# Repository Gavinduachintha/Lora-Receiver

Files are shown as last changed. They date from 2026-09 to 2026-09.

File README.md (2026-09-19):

# LoRa Tracker

A custom Raspberry Pi Pico 2-based LoRa receiver board designed and built as the **base station receiver for the [WildLife AI project](https://github.com/Gavinduachintha/WildLife_AI)**.

The board receives real-time LoRa packets transmitted by the remote wildlife monitoring unit and provides the hardware interface required for the base station display and power system.

## Project Preview
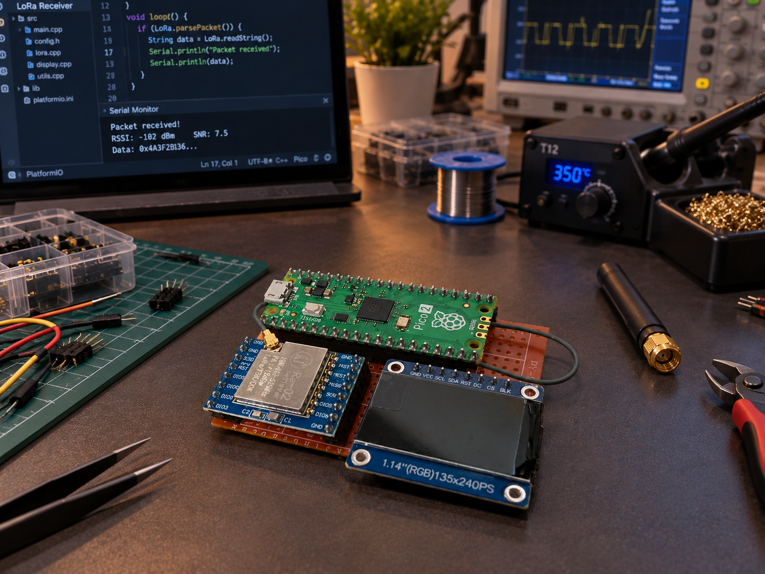
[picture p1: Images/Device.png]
LoRa Tracker Image/board preview


## Overview

The LoRa Tracker is a custom PCB designed to serve as the receiver unit of the WildLife AI system.

It integrates a **Raspberry Pi Pico 2** with dedicated interfaces for the LoRa transceiver, display, and battery power. The board replaces the earlier breadboard-based receiver prototype with a compact and more reliable PCB-based design.

### Main functions

* Receives data from the remote WildLife AI monitoring device through LoRa
* Provides an interface between the LoRa transceiver and Raspberry Pi Pico 2
* Connects to a small color display for receiver-side information
* Provides battery-powered operation
* Includes an onboard power switch
* Provides dedicated headers for external module connections

## Hardware

### Main Controller

* **Raspberry Pi Pico 2**
* RP2350-based microcontroller
* Used as the main controller for the receiver
* Handles incoming LoRa packets and receiver-side processing

### LoRa Interface

The PCB provides dedicated headers for connecting the LoRa transceiver module.

Supported interface signals include:

* MOSI
* MISO
* SCK
* NSS / CS
* RST / RES
* VCC
* GND

### Display Interface

A dedicated 8-pin header is provided for connecting the receiver display.

The interface includes signals such as:

* SCL
* SDA
* BLK
* VCC
* GND

### Power

The board includes:

* 2-pin JST battery connector
* Onboard SPST power switch
* Dedicated power connections for the controller and connected modules

## PCB Design

The board was designed using **KiCad** with the Raspberry Pi Pico 2 positioned as the main controller module.

The PCB provides dedicated connection points for the LoRa module, display, and battery, allowing the receiver to be assembled without the wiring complexity of the original prototype.

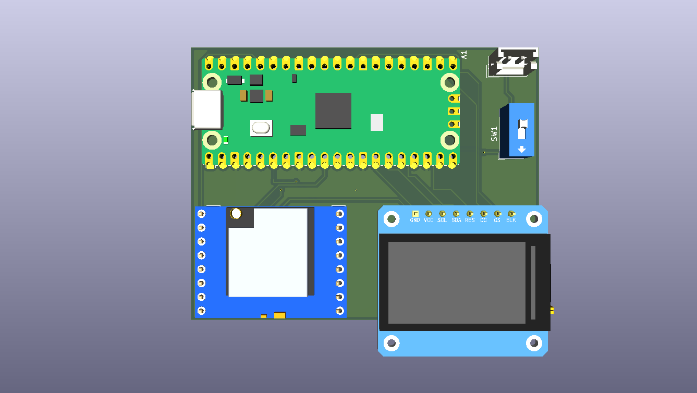
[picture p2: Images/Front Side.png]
Front Side PCB

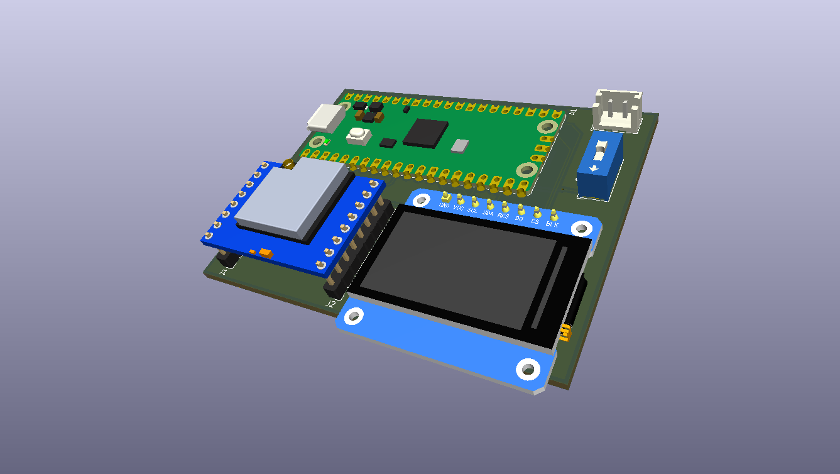
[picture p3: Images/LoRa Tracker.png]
LoRa Tracker assembled/board preview


## Repository Structure

```text
.
├── LoRa Tracker.kicad_pro   # KiCad project
├── LoRa Tracker.kicad_sch   # Schematic
├── LoRa Tracker.kicad_pcb   # PCB layout
└── Images/
    ├── Front Side.png
    └── LoRa Tracker.png
```

## Opening the Project

The project was designed using KiCad.

Open:

```text
LoRa Tracker.kicad_pro
```

from KiCad to access the schematic and PCB layout.

## WildLife AI Integration

This receiver is part of the **WildLife AI** system.

The overall system consists of a remote monitoring device and this receiver/base station.

```text
Remote Wildlife Monitor
        │
        │  LoRa
        ▼
┌─────────────────────┐
│   LoRa Tracker      │
│   Base Station      │
│                     │
│  Raspberry Pi Pico 2│
│  LoRa Interface     │
│  Display Interface  │
└─────────────────────┘
```

The remote unit collects information in the field and transmits it wirelessly through LoRa. The LoRa Tracker receives those packets and acts as the hardware foundation of the base station.

Learn more about the complete system:

[WildLife AI](https://github.com/Gavinduachintha/WildLife_AI)

## Development Workflow

Before manufacturing or modifying the board, the following checks should be performed:

* Review schematic connectivity
* Run KiCad ERC
* Run KiCad DRC
* Verify connector pinouts
* Verify component footprints and orientations
* Check the PCB edge cuts
* Generate fabrication files
* Assemble and test the hardware

## Current Status

The PCB has been designed and built as the **receiver/base station hardware for the WildLife AI project**.

The repository contains the KiCad source files required to inspect and continue development of the board.

## Future Hardware Improvements

Possible future revisions may include:

* Improved printed enclosure
* More integrated LoRa module mounting
* Additional status indicators
* Improved power management
* Further PCB size and connector optimization
* Improved connection distance
* Improved GUI with menu based navigation

## License

This project is licensed under the **Apache License 2.0**.

You are free to use, modify, and distribute this project in accordance with the terms of the license.

See the [`LICENSE`](LICENSE) file for the full license text.

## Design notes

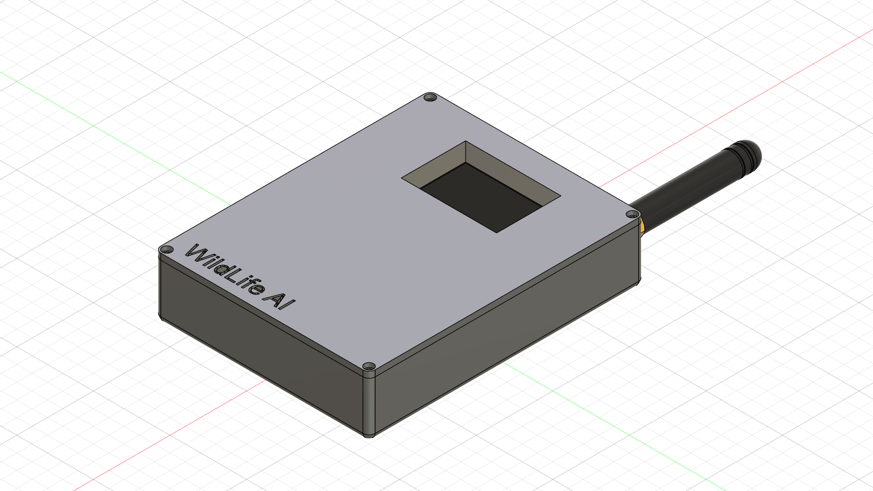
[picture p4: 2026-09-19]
Images/Tracker Box.png

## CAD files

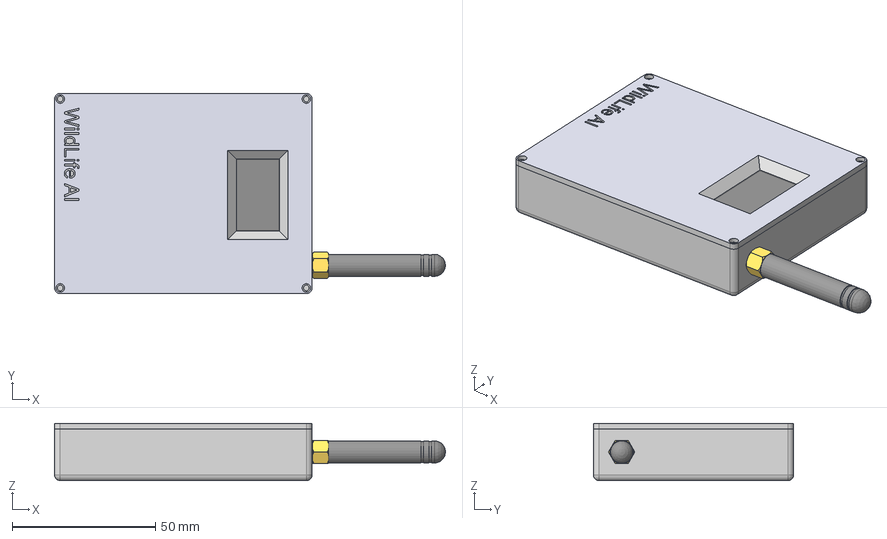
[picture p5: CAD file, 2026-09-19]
CAD File/Tracker Box.step
136.6 x 70.0 x 20.0 mm

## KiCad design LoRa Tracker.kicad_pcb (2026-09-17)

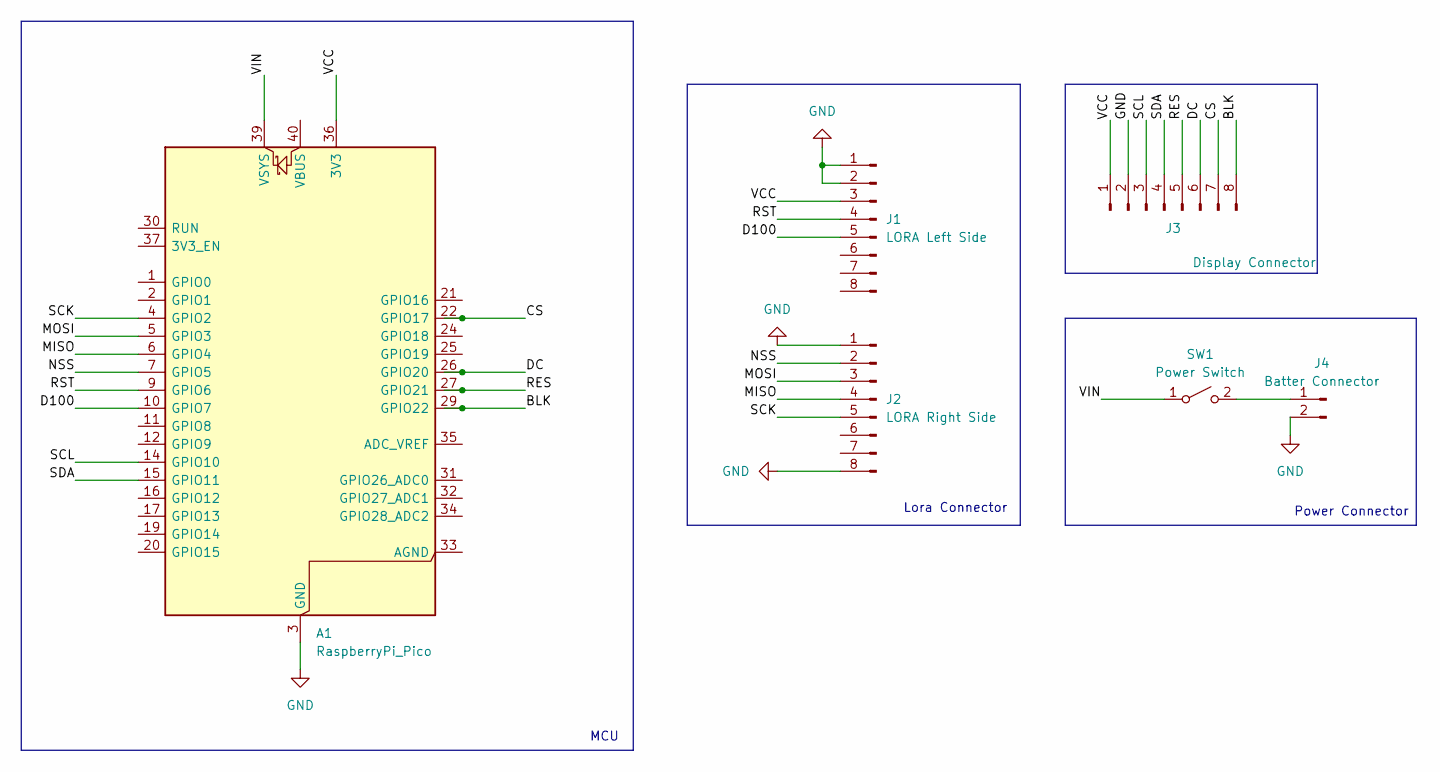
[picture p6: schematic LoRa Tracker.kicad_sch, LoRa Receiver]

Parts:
A1: RaspberryPi_Pico; RaspberryPi_Pico_Common_Unspecified
J1: LORA Left Side; PinHeader_1x08_P2.54mm_Vertical
J2: LORA Right Side; PinHeader_1x08_P2.54mm_Vertical
J3: Display Connector; PinHeader_1x08_P2.54mm_Vertical
J4: Batter Connector; JST_EH_B2B-EH-A_1x02_P2.50mm_Vertical
SW1: Power Switch; SW_DIP_SPSTx01_Slide_9.78x4.72mm_W7.62mm_P2.54mm

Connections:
/BLK: A1.29 (GPIO22), J3.8
/CS: A1.22 (GPIO17), J3.7
/D100: A1.10 (GPIO7), J1.5
/DC: A1.26 (GPIO20), J3.6
/MISO: A1.6 (GPIO4), J2.4
/MOSI: A1.5 (GPIO3), J2.3
/NSS: A1.7 (GPIO5), J2.2
/RES: A1.27 (GPIO21), J3.5
/RST: A1.9 (GPIO6), J1.4
/SCK: A1.4 (GPIO2), J2.5
/SCL: A1.14 (GPIO10), J3.3
/SDA: A1.15 (GPIO11), J3.4
/VCC: A1.36 (3V3), J1.3, J3.1
/VIN: A1.39 (VSYS), SW1.1 (A)
GND: A1.3 (GND), A1.8 (GND), A1.13 (GND), A1.18 (GND), A1.23 (GND), A1.28 (GND), A1.38 (GND), J1.1, J1.2, J2.1, J2.8, J3.2, J4.2
unnamed: J4.1, SW1.2 (B)

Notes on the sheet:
MCU
Lora Connector
Power Connector

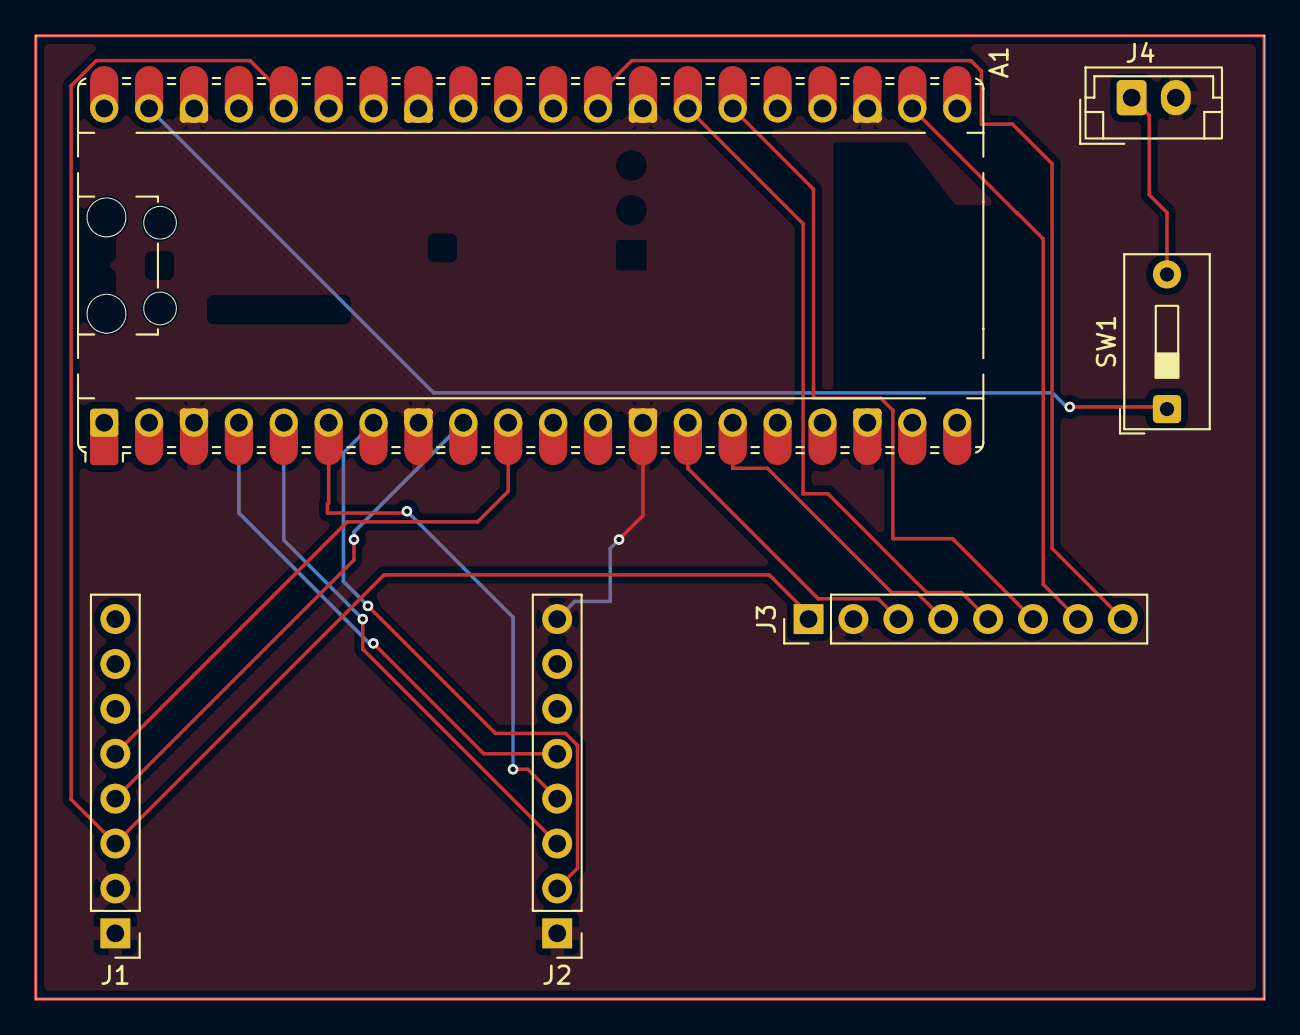
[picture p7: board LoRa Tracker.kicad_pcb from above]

Board: 2 copper layers, 69.5 x 54.5 mm, 6 parts (0 on the bottom side), 16 nets.

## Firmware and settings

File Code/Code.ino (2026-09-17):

#include <SPI.h>
#include <Adafruit_GFX.h>
#include <Adafruit_ST7789.h>

// =====================================================
// SX1278 LORA PINS
// =====================================================
#define LORA_SCK 2
#define LORA_MOSI 3
#define LORA_MISO 4
#define LORA_CS 5
#define LORA_RST 6
#define LORA_DIO0 7

// =====================================================
// ST7789 DISPLAY PINS
// =====================================================
#define TFT_SCK 10
#define TFT_MOSI 11
#define TFT_CS 17
#define TFT_DC 20
#define TFT_RST 21
#define TFT_BLK 22

#define TFT_WIDTH 240
#define TFT_HEIGHT 135

// =====================================================
// SX1278 REGISTERS
// =====================================================
#define REG_FIFO 0x00
#define REG_OP_MODE 0x01
#define REG_FRF_MSB 0x06
#define REG_FRF_MID 0x07
#define REG_FRF_LSB 0x08
#define REG_FIFO_RX_CURRENT 0x10
#define REG_IRQ_FLAGS 0x12
#define REG_RX_NB_BYTES 0x13
#define REG_FIFO_ADDR_PTR 0x0D
#define REG_MODEM_CONFIG1 0x1D
#define REG_MODEM_CONFIG2 0x1E
#define REG_MODEM_CONFIG3 0x26
#define REG_PREAMBLE_MSB 0x20
#define REG_PREAMBLE_LSB 0x21
#define REG_SYNC_WORD 0x39
#define REG_VERSION 0x42

#define LONG_RANGE_MODE 0x80
#define MODE_SLEEP 0x00
#define MODE_STDBY 0x01
#define MODE_RX_CONTINUOUS 0x05

#define IRQ_RX_DONE 0x40
#define IRQ_PAYLOAD_CRC_ERROR 0x20

// =====================================================
// LORA SPI
// =====================================================
SPISettings loraSPI(1000000, MSBFIRST, SPI_MODE0);

// =====================================================
// DISPLAY (SPI1)
// =====================================================
SPIClassRP2040 displaySPI(spi1, 12, TFT_CS, TFT_SCK, TFT_MOSI);

Adafruit_ST7789 tft(&displaySPI, TFT_CS, TFT_DC, TFT_RST);

// =====================================================
// GLOBAL VARIABLES
// =====================================================
uint32_t packetCount = 0;
String lastMessage = "Waiting for message...";
String latitude = "--";
String longitude = "--";
bool hasLocation = false;

// =====================================================
// LORA REGISTER FUNCTIONS
// =====================================================
void writeRegister(uint8_t reg, uint8_t value) {
  SPI.beginTransaction(loraSPI);
  digitalWrite(LORA_CS, LOW);
  SPI.transfer(reg | 0x80);
  SPI.transfer(value);
  digitalWrite(LORA_CS, HIGH);
  SPI.endTransaction();
}

uint8_t readRegister(uint8_t reg) {
  SPI.beginTransaction(loraSPI);
  digitalWrite(LORA_CS, LOW);
  SPI.transfer(reg & 0x7F);
  uint8_t value = SPI.transfer(0x00);
  digitalWrite(LORA_CS, HIGH);
  SPI.endTransaction();
  return value;
}

void resetLoRa() {
  digitalWrite(LORA_RST, LOW);
  delay(10);
  digitalWrite(LORA_RST, HIGH);
  delay(10);
}

void setFrequency(long frequency) {
  uint32_t frf = (uint32_t)((frequency / 32000000.0) * 524288);
  writeRegister(REG_FRF_MSB, (frf >> 16) & 0xFF);
  writeRegister(REG_FRF_MID, (frf >> 8) & 0xFF);
  writeRegister(REG_FRF_LSB, frf & 0xFF);
}

// =====================================================
// DISPLAY FUNCTIONS
// =====================================================
void drawHeader() {
  tft.fillRect(0, 0, 240, 26, ST77XX_BLUE);
  tft.setTextColor(ST77XX_WHITE);
  tft.setTextSize(2);
  tft.setCursor(8, 5);
  tft.print("LORA RECEIVER");
  tft.fillCircle(226, 13, 5, ST77XX_GREEN);
}

void drawStatusBar() {
  tft.fillRect(0, 117, 240, 18, ST77XX_BLACK);
  tft.setTextSize(1);
  tft.setTextColor(ST77XX_WHITE);
  tft.setCursor(5, 122);
  tft.print("433MHz  SF7  BW125");
  tft.setCursor(175, 122);
  tft.print("#");
  tft.print(packetCount);
}

void displayStartup() {
  tft.fillScreen(ST77XX_BLACK);
  tft.setTextColor(ST77XX_CYAN);
  tft.setTextSize(2);
  tft.setCursor(40, 25);
  tft.print("LORA");
  tft.setCursor(30, 50);
  tft.print("RECEIVER");

  tft.setTextColor(ST77XX_WHITE);
  tft.setTextSize(1);
  tft.setCursor(45, 80);
  tft.print("SX1278  |  433 MHz");
  tft.setCursor(60, 100);
  tft.print("Initializing...");
  delay(1500);

  tft.fillScreen(ST77XX_BLACK);
  drawHeader();
  tft.setTextColor(ST77XX_YELLOW);
  tft.setTextSize(1);
  tft.setCursor(25, 55);
  tft.print("Waiting for LoRa message...");
  drawStatusBar();
}

void displayMessage(String message) {
  tft.fillScreen(ST77XX_BLACK);
  drawHeader();

  // ---- Parse location from message ----
  hasLocation = false;
  latitude = "--";
  longitude = "--";

  int latIndex = message.indexOf("LAT:");
  int lonIndex = message.indexOf("LON:");

  if (latIndex != -1 && lonIndex != -1) {
    // Extract Latitude
    int latStart = latIndex + 4;
    int latEnd = message.indexOf(' ', latStart);
    if (latEnd == -1) latEnd = message.length();
    latitude = message.substring(latStart, latEnd);
    latitude.trim();

    // Extract Longitude
    int lonStart = lonIndex + 4;
    int lonEnd = message.indexOf(' ', lonStart);
    if (lonEnd == -1) lonEnd = message.length();
    longitude = message.substring(lonStart, lonEnd);
    longitude.trim();

    hasLocation = true;
  }

  // ---- Main Title ----
  tft.setTextColor(ST77XX_CYAN);
  tft.setTextSize(1);
  tft.setCursor(8, 32);
  tft.print("ALERT");

  tft.setTextColor(ST77XX_WHITE);
  tft.setTextSize(2);
  tft.setCursor(8, 45);
  tft.print("PERSON DETECTED");

  // ---- Location Section ----
  tft.setTextColor(ST77XX_YELLOW);
  tft.setTextSize(1);
  tft.setCursor(8, 72);
  tft.print("LOCATION");

  tft.setTextColor(ST77XX_WHITE);
  tft.setTextSize(1);

  if (hasLocation) {
    tft.setCursor(8, 88);
    tft.print("Lat: ");
    tft.print(latitude);

    tft.setCursor(8, 102);
    tft.print("Lon: ");
    tft.print(longitude);
  } else {
    tft.setCursor(8, 90);
    tft.setTextColor(ST77XX_RED);
    tft.print("GPS: NO FIX");
  }

  drawStatusBar();
}

void displayCRCError() {
  tft.fillScreen(ST77XX_BLACK);
  drawHeader();

  tft.setTextColor(ST77XX_RED);
  tft.setTextSize(2);
  tft.setCursor(50, 50);
  tft.print("CRC ERROR");

  tft.setTextColor(ST77XX_WHITE);
  tft.setTextSize(1);
  tft.setCursor(30, 85);
  tft.print("Corrupted packet received");
  drawStatusBar();
  delay(800);
}

// =====================================================
// LORA SETUP
// =====================================================
void setupLoRa() {
  resetLoRa();

  uint8_t version = readRegister(REG_VERSION);
  Serial.print("SX1278 Version: 0x");
  Serial.println(version, HEX);

  writeRegister(REG_OP_MODE, LONG_RANGE_MODE | MODE_SLEEP);
  delay(10);
  writeRegister(REG_OP_MODE, LONG_RANGE_MODE | MODE_STDBY);

  setFrequency(433000000);

  writeRegister(REG_MODEM_CONFIG1, 0x72);  // BW=125kHz, CR=4/5
  writeRegister(REG_MODEM_CONFIG2, 0x74);  // SF7 + CRC
  writeRegister(REG_MODEM_CONFIG3, 0x04);
  writeRegister(REG_PREAMBLE_MSB, 0x00);
  writeRegister(REG_PREAMBLE_LSB, 0x08);
  writeRegister(REG_SYNC_WORD, 0x12);
  writeRegister(REG_IRQ_FLAGS, 0xFF);

  writeRegister(REG_OP_MODE, LONG_RANGE_MODE | MODE_RX_CONTINUOUS);
  Serial.println("LoRa receiver ready.");
}

// =====================================================
// RECEIVE PACKET
// =====================================================
void receivePacket() {
  uint8_t irq = readRegister(REG_IRQ_FLAGS);

  if (!(irq & IRQ_RX_DONE)) return;

  if (irq & IRQ_PAYLOAD_CRC_ERROR) {
    Serial.println("CRC ERROR");
    displayCRCError();
    writeRegister(REG_IRQ_FLAGS, 0xFF);
    return;
  }

  uint8_t length = readRegister(REG_RX_NB_BYTES);
  uint8_t fifoAddress = readRegister(REG_FIFO_RX_CURRENT);
  writeRegister(REG_FIFO_ADDR_PTR, fifoAddress);

  String message = "";
  Serial.print("Received: ");

  for (uint8_t i = 0; i < length; i++) {
    uint8_t data = readRegister(REG_FIFO);
    Serial.write(data);
    message += (char)data;
  }
  Serial.println();

  packetCount++;
  lastMessage = message;

  displayMessage(message);  // Updated display function

  writeRegister(REG_IRQ_FLAGS, 0xFF);
}

// =====================================================
// SETUP
// =====================================================
void setup() {
  Serial.begin(115200);
  delay(1500);

  // LoRa pins
  pinMode(LORA_CS, OUTPUT);
  digitalWrite(LORA_CS, HIGH);
  pinMode(LORA_RST, OUTPUT);
  digitalWrite(LORA_RST, HIGH);
  pinMode(LORA_DIO0, INPUT);

  // LoRa SPI (SPI0)
  SPI.setSCK(LORA_SCK);
  SPI.setTX(LORA_MOSI);
  SPI.setRX(LORA_MISO);
  SPI.begin();

  // Display backlight
  pinMode(TFT_BLK, OUTPUT);
  digitalWrite(TFT_BLK, HIGH);

  // Display SPI (SPI1)
  displaySPI.setSCK(TFT_SCK);
  displaySPI.setTX(TFT_MOSI);
  displaySPI.begin();

  // Display init
  tft.init(135, 240);
  tft.setRotation(3);  // Landscape 240x135
  tft.fillScreen(ST77XX_BLACK);

  displayStartup();
  setupLoRa();
}

// =====================================================
// MAIN LOOP
// =====================================================
void loop() {
  receivePacket();
  delay(10);
}

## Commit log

2026-09-17 Add project files and images
    [LoRa Tracker.kicad_pcb, LoRa Tracker.kicad_sch]
2026-09-17 Update the real device image
2026-09-19 Add CAD files and sample image
    [Tracker Box.step]
